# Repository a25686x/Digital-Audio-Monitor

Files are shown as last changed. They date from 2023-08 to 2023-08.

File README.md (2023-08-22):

monitor digital audio from SPDIF/AES3 and SDI video source

  CS8416:  select digital audio signals from AES and SDI with BNC and SFP connectors

  SSM3582A:  audio amplifier

  GS2971:  Digital audio demultiplex

  RS2228XN:  select SDI between SFP and BNC conncetor

  ESP8285:  system control

Using following software:

  Kicad 7.0 
  Fusion 360
  Arduino

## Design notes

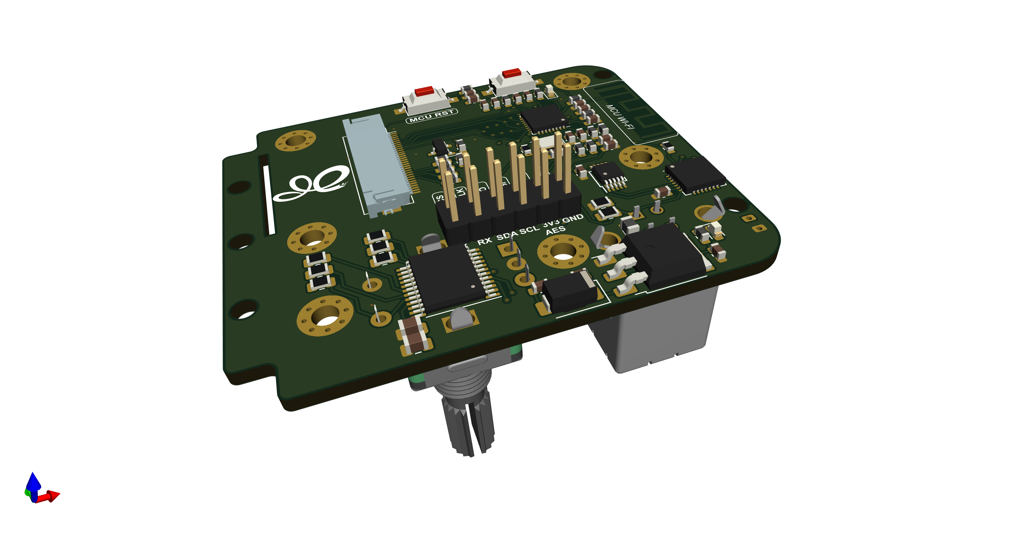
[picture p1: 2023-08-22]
Kicad_Files/MCU/MCU_ROTARY_LCD_CM108AH_20230812EV.png

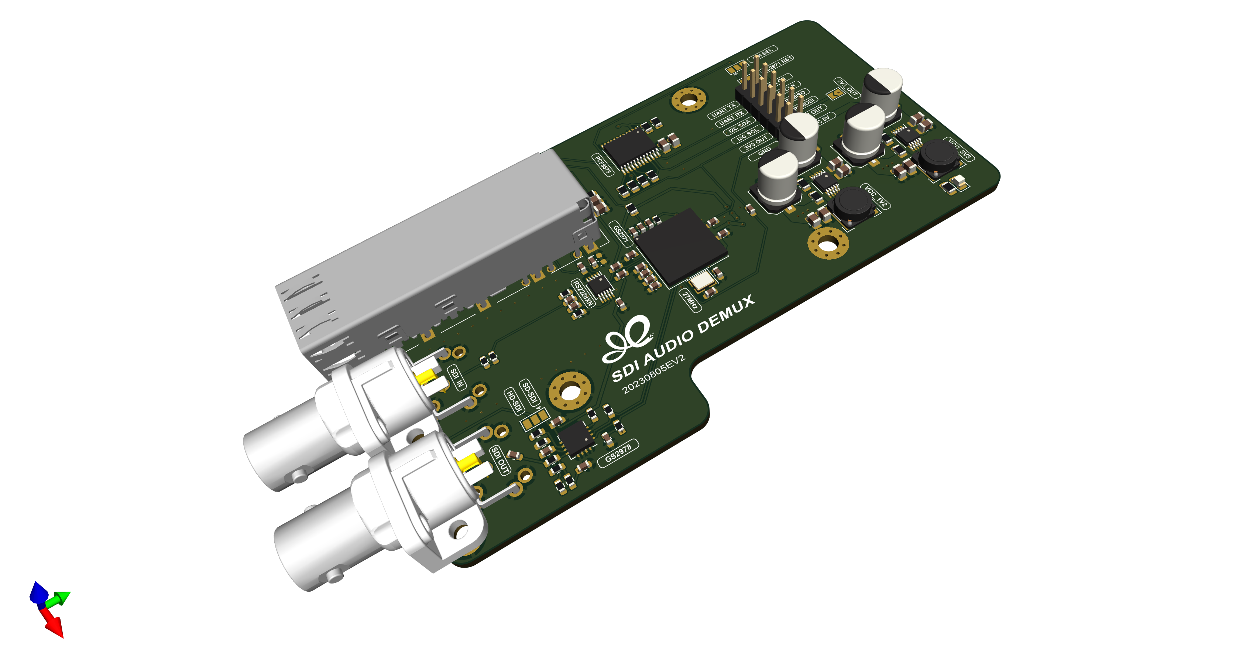
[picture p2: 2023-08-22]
Kicad_Files/SDI_DEMUX_RS2228XN_20230805EV.png

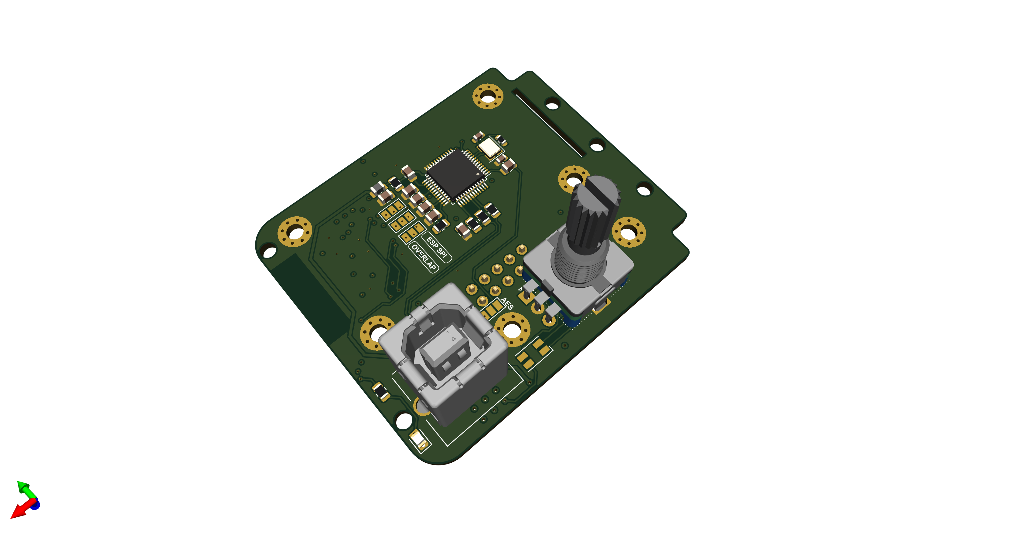
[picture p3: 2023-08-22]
Kicad_Files/MCU/MCU_ROTARY_LCD_CM108AH_20230812EV2.png

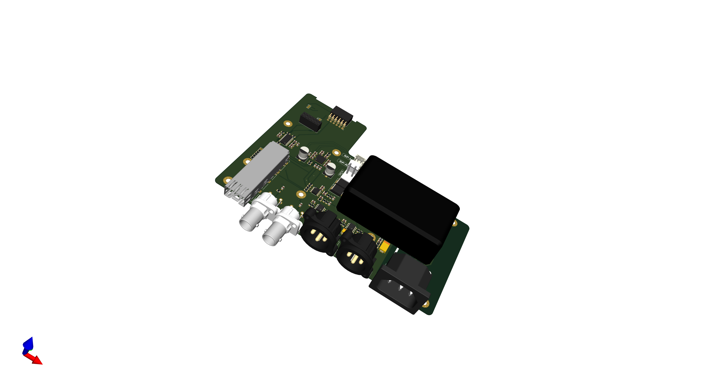
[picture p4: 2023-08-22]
Kicad_Files/MainBoard/AudioMonitor_MB_20230804EV.png

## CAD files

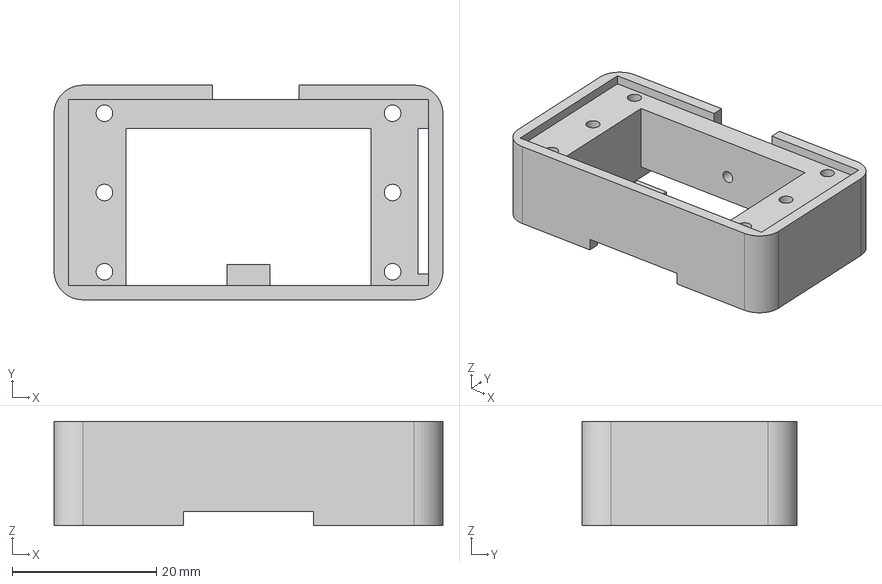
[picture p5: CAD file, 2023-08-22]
3D_STEP_Files/AudioMonitor_LCD_BASE_20230813EV v54.step
54.0 x 29.8 x 14.5 mm

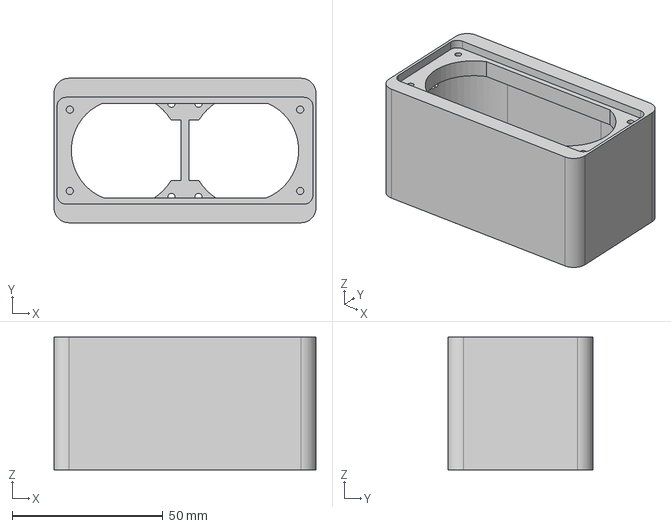
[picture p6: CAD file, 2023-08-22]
3D_STEP_Files/AudioMonitor_BOX_20230811EV v42.step
87.0 x 48.0 x 44.0 mm

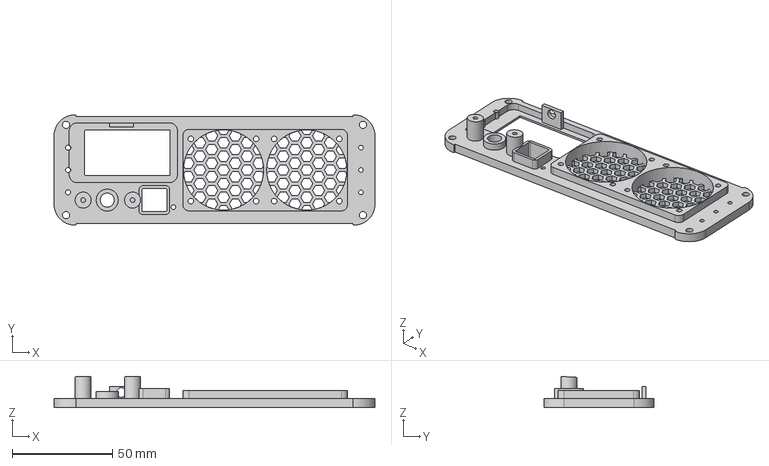
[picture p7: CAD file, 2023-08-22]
3D_STEP_Files/AudioMonitor_Panel_20230814EV_END_+0.5MM.step
160.0 x 55.0 x 15.5 mm

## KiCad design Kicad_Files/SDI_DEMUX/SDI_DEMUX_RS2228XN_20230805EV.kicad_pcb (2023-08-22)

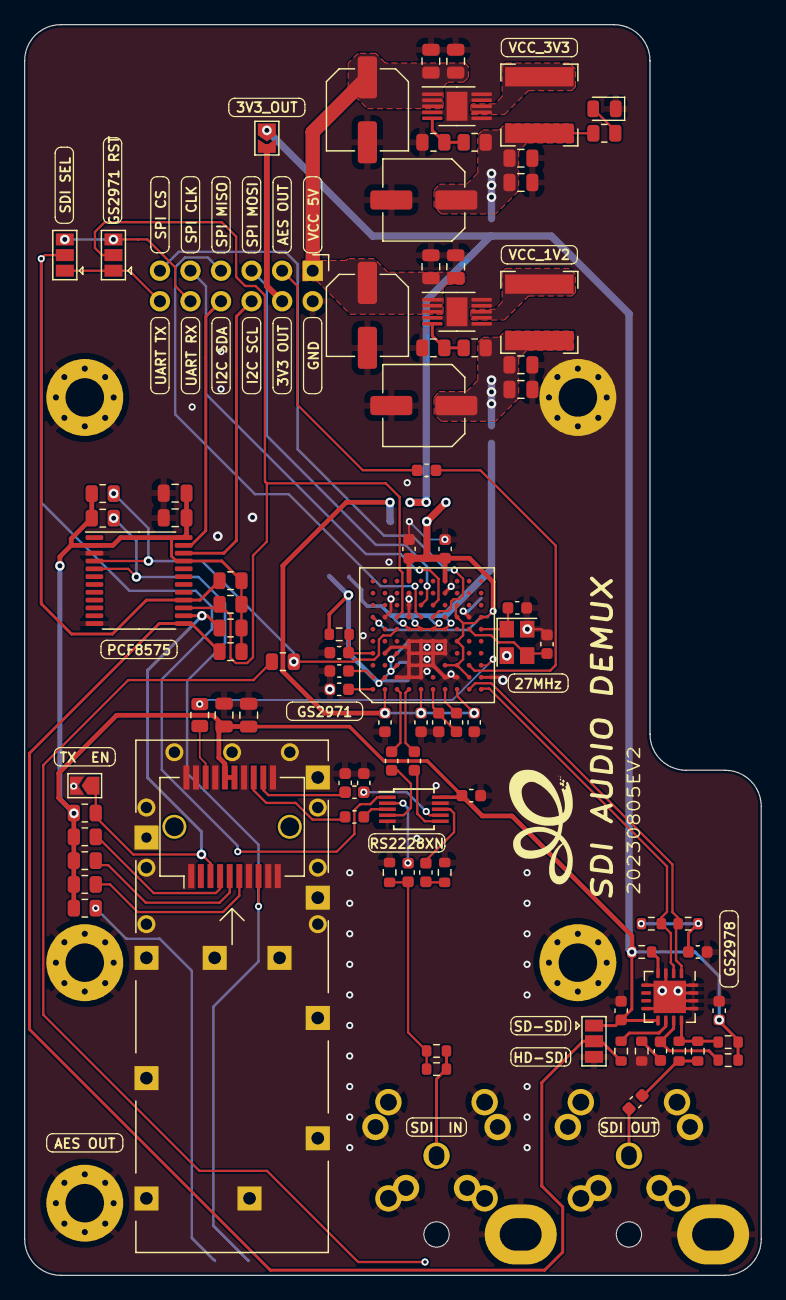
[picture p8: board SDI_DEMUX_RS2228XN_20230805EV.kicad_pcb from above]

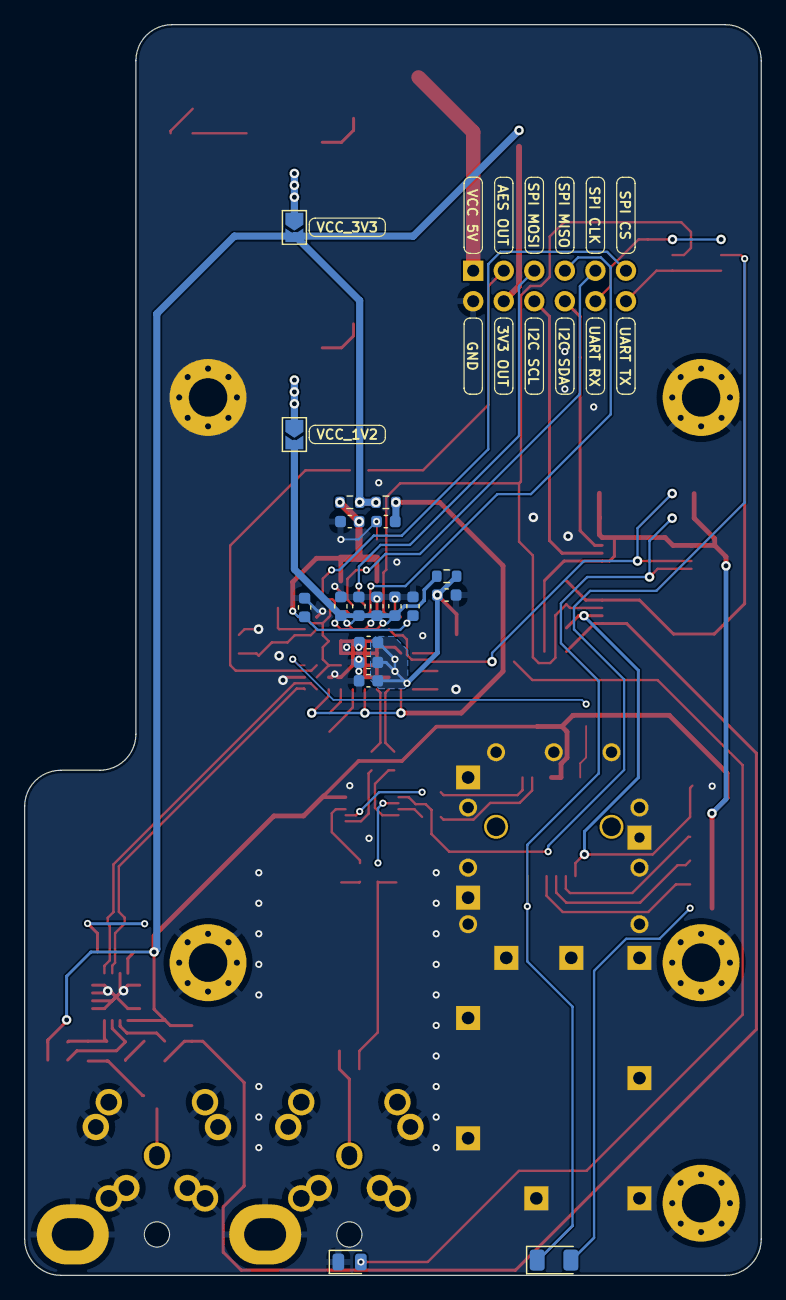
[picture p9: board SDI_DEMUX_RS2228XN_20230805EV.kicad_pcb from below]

Board: 2 copper layers, 61.2 x 104.0 mm, 118 parts (19 on the bottom side), 68 nets.

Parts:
C10, C26, C31, C42, C49, C51: 105; C_0603_1608Metric
C11, C12, C13, C14, C15, C16, C17, C27, C28, C29, C32, C33, C34, C35, C47, C48, C57: 10n; C_0603_1608Metric
C18: 226; C_0603_1608Metric
C41, C100, C101: 474; C_0603_1608Metric
C43, C44: 16p; C_0603_1608Metric
C50, C52: 475; C_0603_1608Metric
C105: 104; C_0603_1608Metric
C2701, C3302: 106; C_0805_2012Metric
C2702, C3102, C3202, C3301: 104; C_0805_2012Metric
C2711, C2712, C2721, C2722, C2723, C2724, C2731: 106; C_0603_1608Metric
C3101, C3106, C3201, C3206: 105; C_0805_2012Metric
C3103, C3104, C3203, C3204: 107; CP_Elec_6.3x7.7_20230725EV
C3105, C3205: 10n; C_0805_2012Metric
D102, D205: LED; LED_0805_2012Metric
D2701: Fiber RX OK(GREEN); LED_1206_3216Metric
J2701: SDI IN; Connector_SFP_and_Cage_UserEco1_20230723EV
J2702: SDI_OUT; BCJ-BPLHKA_TOP_UserEco1_20230722EV
J2705: SDI_IN; BCJ-BPLHKA_TOP_UserEco1_20230722EV
J3001: Conn_02x06_Odd_Even; PinHeader_2x06_P2.54mm_Vertical
JP1, JP3, JP2702: SolderJumper_3_Open; SolderJumper-3_P1.3mm_Open_Pad1.0x1.5mm
JP2, JP3001, JP3101, JP3201: SolderJumper_2_Open; SolderJumper-2_P1.3mm_Open_TrianglePad1.0x1.5mm
L3: 6.2n; R_0603_1608Metric
L4: 5.6n; R_0603_1608Metric
L3101, L3201: L; L_Bourns-SRN6028
MB3, MB4, MB5, MB6, MB7: MB; MountingHole_3.2mm_M3_Pad_Via_Eco1_20230801EV
R2, R10, R11, R50: 0R; R_0603_1608Metric
R3: 0R; R_0805_2012Metric
R7: 105R; R_0603_1608Metric
R40: 750R; R_0603_1608Metric
R41, R42, R43, R44, R45, R47: 75R; R_0603_1608Metric
R46: 37.4R; R_0603_1608Metric
R48, R49: 49.9; R_0603_1608Metric
R100, R205: 4.7k; R_0805_2012Metric
R2701, R2702, R2703, R2704: 4.7K; R_0805_2012Metric
R2705: 1K; R_0805_2012Metric
R3101: 450K; R_0805_2012Metric
R3102, R3201, R3202, R3301, R3302, R3303, R3304, R3311, R3312: 100K; R_0805_2012Metric
U1: GS2971; BGA-100_11.0x11.0mm_Layout10x10_P1.0mm_Ball0.5mm_Pad0.4mm_N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
U7: GS2978; QFN-16-1EP_4x4mm_P0.65mm_EP2.7x2.7mm
U2702: RS2228XN; MSOP-10_3x3mm_P0.5mm
U3101, U3201: AP2420; MSOP-10-1EP_3x3mm_P0.5mm_EP1.73x2.40mm_20230801EV
U3301: PCF8575PW; TSSOP-24_6.1x7.8mm_P0.65mm
Y1: 27M; Crystal_SMD_3225-4Pin_3.2x2.5mm

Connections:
/+1.2V: C14.1, C15.1, C16.1, C17.1, JP3201.2 (B), R10.2, U1.D6 (CORE_VDD), U1.E6 (CORE_VDD), U1.F6 (CORE_VDD), U1.G6 (CORE_VDD)
/+1.2VA: C26.1, C27.1, C28.1, C29.1, R7.2, R10.1, U1.B2 (PLL_VDD), U1.C3 (PLL_VDD), U1.C4 (PLL_VDD)
/+3.3VA: C10.1, C11.1, C12.1, C13.1, R2.1, U1.B1 (A_VDD), U1.E1 (SDI_VDD), U1.H1 (BUF_VDD)
/AES_SFP_TX+: J2701.18 (TD+), R3.1
/AOUT_1/2: C105.2, J3001.4
/AOUT_3/4: R3.2, U1.K3 (AOUT_3/4)
/GS2971_IN+: C2711.2, U1.C1 (SDI+)
/GS2971_IN-: C2712.2, U1.D1 (SDI-)
/GS2971_RST: JP1.2 (C), R3303.1, U1.C7 (RESET-), U3301.15 (P12)
/GS2971_STAT5: R205.2, R3311.2, U1.C6 (STAT5), U3301.4 (P00)
/IO_VDD: C31.1, C32.1, C33.1, C34.1, C35.1, R11.1, U1.A7 (IO_VDD), U1.D10 (IO_VDD), U1.G3 (RC_BYP), U1.G10 (IO_VDD), U1.H3 (AUDIO_EN/DIS), U1.H5 (TIM_861), U1.H7 (20BIT_10BIT), U1.H8 (IOPROC_EN/DIS), U1.J2 (SDO_EN/DIS), U1.K7 (IO_VDD)
/MCU_3V3_OUT: J3001.3, JP3001.2 (B)
/MCU_I2C_SCL: J3001.5, U3301.22 (SCL)
/MCU_I2C_SDA: J3001.7, U3301.23 (SDA)
/MCU_SPI_CLK: J3001.10, U1.F8 (SCLK_TCK)
/MCU_SPI_CS: J3001.12, U1.F7 (CS_TMS)
/MCU_SPI_MISO: J3001.8, U1.E7 (SDOUT_TDO)
/MCU_SPI_MOSI: J3001.6, U1.E8 (SDIN_TDI)
/MCU_UART_RX: J3001.9, JP1.3 (B), JP2702.3 (B)
/MCU_UART_TX: J3001.11, JP1.1 (A), JP2702.1 (A)
/SDI_IN+: C49.2, U2702.2 (HSD0_P)
/SDI_IN-: C51.2, U2702.8 (HSD0_M)
/SDI_INPUT_SELECT: JP2702.2 (C), R3304.1, U2702.1 (SEL), U3301.16 (P13)
/SDO+: R49.1, U1.J1 (SDO+), U7.1 (SDI+)
/SDO-: R48.1, U1.K1 (SDO-), U7.2 (SDI-)
/SD_HD_SLEW: JP3.2 (C), R50.2, R3301.1, U3301.13 (P10)
/SFP_RD+: C2721.1, J2701.13 (RD+)
/SFP_RD-: C2722.1, C2723.2, J2701.12 (RD-)
/SFP_RX_LOSS: D2701.1 (K), J2701.8 (RX_LOS), R3312.2, U3301.5 (P01)
/SFP_TX_DISABLE: J2701.3 (TX_DISABLE), JP2.1 (A), R2704.2, R3302.1, U3301.14 (P11)
/VCC5V_IN: C3101.1, C3102.1, C3103.1, C3201.1, C3202.1, C3203.1, J3001.2, U3101.1 (EN), U3101.2 (VDD), U3101.3 (PVDD), U3201.1 (EN), U3201.2 (VDD), U3201.3 (PVDD)
/VCC_3.3V: C47.1, C48.1, C2701.1, C2702.1, C2731.1, C3301.1, C3302.1, J2701.15 (VccR), J2701.16 (VccT), JP3.1 (A), JP3001.1 (A), JP3101.2 (B), R2.2, R11.2, R40.1, R41.1, R43.1, R2701.1, R2702.1, R2703.1, R2704.1, R2705.2, R3301.2, R3302.2, R3303.2, R3304.2, R3311.1, R3312.1, U7.9 (VCC), U2702.10 (VCC), U3301.2 (A1), U3301.21 (A0), U3301.24 (VCC)
GNDD: C10.2, C11.2, C12.2, C13.2, C14.2, C15.2, C16.2, C17.2, C18.2, C26.2, C27.2, C28.2, C29.2, C31.2, C32.2, C33.2, C34.2, C35.2, C41.1, C42.1, C43.2, C44.1, C47.2, C48.2, C57.2, C101.1, C2701.2, C2702.2, C2723.1, C2724.1, C2731.2, C3101.2, C3102.2, C3103.2, C3104.2, C3105.2, C3106.2, C3201.2, C3202.2, C3203.2, C3204.2, C3205.2, C3206.2, C3301.2, C3302.2, D102.1 (K), D205.1 (K), J2701.1 (VeeT), J2701.7 (RS0), J2701.9 (RS1), J2701.10 (VeeR), J2701.11 (VeeR), J2701.14 (VeeR), J2701.17 (VeeT), J2701.19 (TD-), J2701.20 (VeeT), J2701.CAGE, J2702.2 (Ext), J2705.2 (Ext), J3001.1, JP2.2 (B), JP3.3 (B), MB3.1, MB4.1, MB5.1, MB6.1, MB7.1, R44.1, R45.2, R46.2, R3102.2, R3202.2, U1.B4 (VCO_GND), U1.B7 (IO_GND), U1.C2 (A_GND), U1.D2 (A_GND), U1.D3 (A_GND), U1.D4 (PLL_GND), U1.D5 (CORE_GND), U1.D7 (SW_EN), U1.D8 (JTAG/HOST), U1.D9 (IO_GND), U1.E2 (SDI_GND), U1.E3 (A_GND), U1.E4 (PLL_GND), U1.E5 (CORE_GND), U1.F3 (A_GND), U1.F4 (PLL_GND), U1.F5 (CORE_GND), U1.G2 (A_GND), U1.G4 (CORE_GND), U1.G5 (CORE_GND), U1.G9 (IO_GND), U1.H2 (BUF_GND), U1.J7 (IO_GND), U1.K2 (STANDBY), U7.3 (GND), U7.5 (NC), U7.8 (NC), U7.13 (NC), U7.14 (NC), U7.15 (NC), U7.16 (NC), U7.17 (TAB), U2702.5 (GND), U2702.9 (nOE), U3101.4 (GND), U3101.6 (GND), U3101.9 (PGND), U3101.10 (PGND), U3101.11 (GND), U3201.4 (GND), U3201.6 (GND), U3201.9 (PGND), U3201.10 (PGND), U3201.11 (GND), U3301.3 (A2), U3301.12 (GND), Y1.2, Y1.4
unnamed: C49.1, L3.2, R42.1, R45.1
unnamed: C50.2, R44.2
unnamed: C51.1, R46.1
unnamed: C52.1, L4.2, R47.1
unnamed: C57.1, R48.2, R49.2
unnamed: D102.2 (A), R100.2
unnamed: D205.2 (A), R205.1
unnamed: D2701.2 (A), R2705.1
unnamed: J2701.6 (MOD_ABS), R2703.2
unnamed: J2701.5 (SCL), R2702.2
unnamed: J2701.4 (SDA), R2701.2
unnamed: C52.2, J2702.1 (In)
unnamed: J2705.1 (In), L3.1, R42.2
unnamed: C3104.1, C3105.1, C3106.1, JP3101.1 (A), L3101.2, R100.1, R3101.1
unnamed: C3204.1, C3205.1, C3206.1, JP3201.1 (A), L3201.2, R3201.1
unnamed: L3101.1, U3101.7 (LX), U3101.8 (LX)
unnamed: L3201.1, U3201.7 (LX), U3201.8 (LX)
unnamed: C100.1, C101.2, U1.F1 (AGC+)
unnamed: C100.2, U1.G1 (AGC-)
unnamed: C105.1, U1.J3 (AOUT_1/2)
unnamed: C41.2, U1.A2 (LF)
unnamed: C42.2, U1.A1 (VBG)
unnamed: C18.1, R7.1, U1.A4 (VCO_VDD)
unnamed: C44.2, U1.K6 (XTAL1), Y1.1
unnamed: C43.1, U1.J6 (XTAL2), Y1.3
unnamed: R40.2, U7.4 (RSET)
unnamed: L4.1, R41.2, R47.2, U7.12 (SDO+)
unnamed: C50.1, R43.2, U7.11 (SDO-)
unnamed: R50.1, U7.10 (SD/HD)
unnamed: C2712.1, U2702.6 (D_N)
unnamed: C2711.1, U2702.4 (D_P)
unnamed: C2722.2, C2724.2, U2702.7 (HSD1_M)
unnamed: C2721.2, U2702.3 (HSD1_P)
unnamed: R3101.2, R3102.1, U3101.5 (FB)
unnamed: R3201.2, R3202.1, U3201.5 (FB)

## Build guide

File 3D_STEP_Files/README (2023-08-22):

step files export from Fusion 360 for 3D print

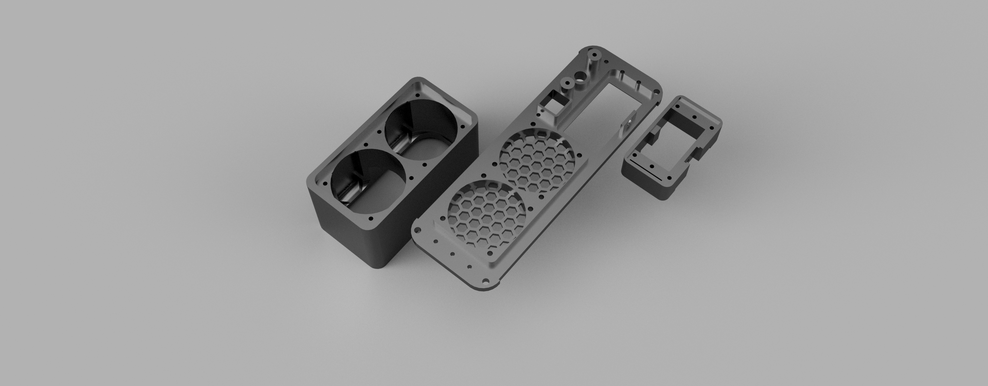
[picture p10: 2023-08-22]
3D_STEP_Files/AudioMonitor_Panel_20230719EV v54.png

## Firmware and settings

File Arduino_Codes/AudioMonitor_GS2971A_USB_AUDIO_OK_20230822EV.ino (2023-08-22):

#include "Arduino.h"
#include "PCF8575.h"
#include <Wire.h>
#include <Adafruit_PWMServoDriver.h>
#include <SPI.h>
#include <EEPROM.h>


#include <TFT_eSPI.h>




//顶部标题信息显示
String str_TopHeader = "AUDIO   GEARBOX   PRO";



//GS2971A SPI数据读取
char SPI_READ_VALUE[48] = {0};


//实例化TFT_eSPI
TFT_eSPI tft  = TFT_eSPI();

//LCD时间显示最大计数复位
#define MAX_TIME_COUNT    86400



//最大音量限制
#define SSM3582A_MAX_OUTPUT_VOLUME   245


//信号数量定义
#define INPUT_SIGNAL_COUNT   5

//信号接口及信号类型定义
String str_AudioSource[INPUT_SIGNAL_COUNT][2] = {
  {"AES", "BNC-1"},
  {"AES", "SFP-1"},
  {"SDI", "BNC-2"},
  {"SDI", "SFP-2"},
  {"USB", "FRONT"}
};








//CS8416复位控制引脚:GPIO3(ESP8285_UART_RX)
//CS8416复位控制引脚:GPIO1(ESP8285_UART_TX)
//CS8416复位控制引脚:GPIO2(ESP8285_SPI_CS)


//*********GS2971与CS8416采用同一复位引脚*********//
#define CS8416_GS2971_RESET_PIN    1










//CS8416锁定状态ESP8285检测GPIO端口(GPIO16)
//设置cs8416寄存器6第4位(UNLOCKM)掩码为1，设置GPIO0输出为RERR，通过CS8416 GPIO0端口输出信号锁定状态
#define CS8416_LOCKED_DETECT_PIN  16
//CS8416上次检测锁定状态
int   last_CS8416_lock_status = 0;
//CS8416锁定状态
int   CS8416_lock_status = 0;


//CS8416 I2C地址
#define  CS8416_I2C_ADDRESS   0x14


//信号输入端口定义
int RX_PORT[INPUT_SIGNAL_COUNT] = {0x00, 0x08, 0x10, 0x10, 0x18};

//信号输出端口定义
int TX_PORT[INPUT_SIGNAL_COUNT] = {0x00, 0x01, 0x02, 0x02, 0x03};


//BNC接口及FC接口AES信号输出源索引
//  0:  BNC接口输入
//  1:  FC光纤输入
//  2:  BNC接口SDI输入音频解嵌输出
//  3:  FC光纤接口SDI输入音频解嵌输出
int   n_AES_TX_Index = 0;

//监听AES信号输入源索引
//  0:  BNC接口输入
//  1:  FC光纤输入
//  2:  BNC接口SDI输入音频解嵌输出
//  3:  FC光纤接口SDI输入音频解嵌输出
int   n_AES_monitor_Index = 2;






#include <PolledTimeout.h>

#define ESP8285_SDA_PIN 4
#define ESP8285_SCL_PIN 5

//ESP8285 I2C地址(可选)
const int16_t ESP8285_I2C_MASTER_ADDRESS = 0x42;





//SSM3582A初始音量设置
int n_SSM3582A_vol = 0x80;

//GS12070 SPI Control SS PIN
int GPIO_SPI_CS = 10;














//LED闪烁间隔
unsigned long LedFlash_Time = {0};
int   LedFlashControl = 0;
int   LedFlashInterval = 500;
int   FlashInterval = 500;










//信息刷新显示间隔
int  infoUpdate_Interval = 1000;
unsigned long infoUpdate_Time = 0;





















//**********串口数据读取**********
char str_ReadCommand[200];
int nIndex = 0;




/*************************************************************/
//TLC5615 SPI控制引脚
const int CS_PIN = 2;   // 片选引脚
const int CLK_PIN = 14;  // 时钟引脚
const int DATA_PIN = 13; // 数据引脚
/*************************************************************/





/*************************************************************/
//旋转编码器变量定义
int encoderPos = 0;
//前一个计数值（-----当计数值未变化时不刷新显示或执行操作-----）
int last_encoderPos = 0;

//编码器状态
int encoderState = 0;
int lastEncoded = 0;

//编码器各引脚状态值
int encoderPinAState;
int encoderPinBState;
int encoderPinSWState;

//编码器SW按钮按下计数
int   n_EC11_Index = 0;



//数值是否改变标志
bool  b_value_changed = false;
/*************************************************************/






/*
  0x18ce  //午夜蓝
  0x22f   //水手蓝
  0x18a   //普鲁士蓝
  0x194
  0x4004    //勃艮第红
  0x5345    //暗橄榄绿
  0x6199    //紫水晶色
  0x49c0    //咖啡色
  0x62ca    //铁灰色
  0x48e0    //椰褐色
  0xcfe0    //亮柠檬色
  0x9806    //紫红
  0xa7f9    //苍色
  0xc618    //银色
  0xf7be    //白烟色
  0xcaa0    //燃橙
  0xff59    //杏仁白
*/

//顶部标题显示背景色
int top_BG = 0x9806; //紫红
//int top_BG = 0xcfe0; //亮柠檬色
int top_FG = TFT_WHITE;
//int top_FG = 0xa7f9; //苍色
//int top_FG = 0xcfe0; //亮柠檬色
uint8_t top_Font = 4;
int top_MC_OFFSET = 3; //文字显示垂直偏移





//频率显示背景色
int freq_BG = 0x48e0; //椰褐色
int freq_FG = 0xc618;  //银色
uint8_t freq_Font = 4;
int freq_MC_OFFSET = 5; //文字显示垂直偏移

//电压显示背景色
int voltage_BG = 0x18a; //普鲁士蓝
//int voltage_FG = TFT_WHITE;
int voltage_FG = 0xc618;  //银色
uint8_t voltage_Font = 4;
int voltage_MC_OFFSET = 3; //文字显示垂直偏移




//信号源选择显示背景色
int audio_BG = 0x18a; //普鲁士蓝
int audio_FG = 0xc618;  //银色
uint8_t audio_Font = 4;
int audio_MC_OFFSET = 3; //文字显示垂直偏移




//电流显示背景色
int amps_BG = 0x4004; //勃艮第红
//int amps_FG = TFT_WHITE;
int amps_FG = 0xc618;  //银色
uint8_t amps_Font = 4;
int amps_MC_OFFSET = 3; //文字显示垂直偏移




//输出功率显示背景色
int fwd_BG = 0x5345;  //暗橄榄绿
//int fwd_FG = 0xcaa0;  //燃橙
int fwd_FG = 0xff59;  //杏仁白
//int fwd_FG = 0xc618;  //银色
//int fwd_FG = 0xf7be;  //白烟色
uint8_t fwd_Font = 4;
int fwd_MC_OFFSET = 8; //文字显示垂直偏移



//运行时间显示背景色
int time_BG = 0x2a69; //暗岩灰
int time_BG2 = 0x11;  //暗蓝
int time_FG = 0xcfe0; //亮柠檬色
uint8_t time_Font = 7;

//时钟刷新定时间隔
unsigned long clock_Time = 0;
int   ClockInterval = 1000;


//系统启动计时
unsigned long n_StartUpTime = 0;



//LCD屏背光设置
int LCD_BLK_VALUE = 140;

//LCD屏幕保护等待时间
unsigned long ScreenSave_Time = 0;
int   ScreenSave_Interval = 30000;



//面板键盘按钮数量定义
#define   KEY_COUNT   6


//按钮消除抖动时间设置
const int DEBOUNCE_DELAY = 50;

//按钮长按时间定义
const int LONG_PRESS_TIME = 2000;




//按钮上一次处于稳定状态时引脚电平
int lastSteadyState[KEY_COUNT + 1] = {HIGH};
//按钮上一次抖动状态时引脚电平
int lastFlickerableState[KEY_COUNT + 1] = {HIGH};
//按钮当前状态引脚电平
int currentState[KEY_COUNT + 1];

//按钮上一次处于抖动状态时间
unsigned long lastDebounceTime[KEY_COUNT + 1] = {0};
//按钮上一次按下时间
unsigned long prevPressTime[KEY_COUNT + 1] = {0};
//当前时间
unsigned long curTime[KEY_COUNT + 1] = {0};









/**********GS2971音频解嵌SPI控制参数**********/
//HD MODE AES OUT CONFIG
//char HD_AES_OUT_CONFIG[4] = {0x02, 0x00, 0x0f, 0x04};
char HD_AES_OUT_CONFIG[4] = {0x02, 0x00, 0x00, 0x00};
//SD MODE AES OUT CONFIG
//char SD_AES_OUT_CONFIG[4] = {0x04, 0x08, 0x00, 0x00};
char SD_AES_OUT_CONFIG[4] = {0x04, 0x08, 0xff, 0x00};

//SATA0-SATA2 PORT MODE SET
//0_XXXXX_XXXXX_XXXXX
//4-0   SATA0_CONFIG
//9-5   SATA1_CONFIG
//14-10 SATA2_CONFIG

//00011:  LOCKED
char SATA_0_1_2_CONFIG[4] = {0x00, 0x08, 0x0c, 0x63};

//SATA3-SATA5 PORT MODE SET
//0_XXXXX_XXXXX_XXXXX
//4-0   SATA3_CONFIG
//9-5   SATA4_CONFIG
//14-10 SATA5_CONFIG

//00011:  LOCKED
char SATA_3_4_5_CONFIG[4] = {0x00, 0x09, 0x0c, 0x63};



//AES OUTPUT CHANNEL CONFIG
//CH1+CH2:  0x208
//CH3+CH4:  0x692
//CH5+CH6:  0xB2C
//CH7+CH8:  0xFBE
//CH1+CH1:  0x000
//CH2+CH2:  0x249
//CH3+CH3:  0x492
//CH4+CH4:  0x6DB
//CH5+CH5:  0x924
//CH6+CH6:  0xB6D
//CH7+CH7:  0xDB6
//CH8+CH8:  0xFFF
char SD_AES_OUT_SELECT_CH1234[4] = {0x04, 0x09, 0x02, 0x08};
char SD_AES_OUT_SELECT_CH5678[4] = {0x04, 0x0A, 0x02, 0x08};

char HD_AES_OUT_SELECT_CH1234[4] = {0x02, 0x0A, 0x02, 0x08};
char HD_AES_OUT_SELECT_CH5678[4] = {0x02, 0x0B, 0x02, 0x08};



char  SPI_CMD[48] = {
  0x80, 0x1F, 0xff, 0xff,
  0x80, 0x20, 0x00, 0x00,
  0x80, 0x21, 0xff, 0xff,
  0x80, 0x22, 0x00, 0x00,
  //0x02, 0x00, 0x0f, 0x04,   //HD AES OUT
  0x02, 0x00, 0x00, 0x00,   //HD AES OUT
  //0x04, 0x08, 0x00, 0x00,   //SD AES OUT
  0x04, 0x08, 0xff, 0x00,   //SD AES OUT(auto 20bit or 24bit)
  0x00, 0x08, 0x0c, 0x63,   //SATA_0_1_2 CONFIG
  0x00, 0x09, 0x0c, 0x63,   //SATA_3_4_5 CONFIG
  0x04, 0x09, 0x02, 0x08,   //SD_AES_OUT_SELECT_CH1234
  0x04, 0x0A, 0x02, 0x08,   //SD_AES_OUT_SELECT_CH5678
  0x02, 0x0A, 0x02, 0x08,   //HD_AES_OUT_SELECT_CH1234
  0x02, 0x0B, 0x02, 0x08,   //HD_AES_OUT_SELECT_CH5678
};



int i_CH = 0;
char CH[12] = {
  0x0000, 0x0249, 0x0492, 0x06db,
  0x0924, 0x0b6d, 0x0db6, 0x0fff,
  0x0208, 0x0692, 0x0b2c, 0x0fbe
};













/***************************2023-08-04******************************/

//SDI子卡GPIO输入输出控制PCF8575 I2C地址
int SDI_CONTROL_PCF8575_I2C_ADDRESS = 0x23;

//SDI子卡GPIO输入输出控制PCF8575实例化
PCF8575 SDI_control_pcf8575(SDI_CONTROL_PCF8575_I2C_ADDRESS);

//GS2971_STAT5状态监测GPIO端口编号
int GS2971_STAT5_STATUS_PORT = 0;
//STAT5端口状态
int GS2971_STAT5_STATUS = 0;

//SFP接收信号中断状态监测GPIO端口编号
int SFP_RX_LOSS_STATUS_PORT = 1;
//RX Loss端口状态
int SFP_RX_LOSS_STATUS = 0;

//LMH0302 SD/HD SLEW控制GPIO端口编号
int LMH0302_SLEW_CONTROL_PORT = 8;

//SFP发送信号允许控制GPIO端口编号
int SFP_TX_ENABLE_PORT = 9;

//GS2971芯片复位控制GPIO端口编号
int GS2971_RESET_CONTROL_PORT = 10;

//RS22228XN SDI输入选择控制GPIO端口编号
int RS2228XN_INPUT_SELECT_PORT = 11;

//GS2971A SPI 控制片选引脚ESP8285 GPIO端口编号
int ESP8285_GS2971_GPIO_SPI_CS = 2;


//SDI子卡PCF8575状态一次性读取
PCF8575::DigitalInput SDI_pcf8575_di;






//AudioMonitor音频功放键盘检测PCF8575 I2C地址
int PCF8575_I2C_ADDRESS = 0x21;

//面板旋转编码器状态监测PCF8575实例化
PCF8575 pcf8575(PCF8575_I2C_ADDRESS);


//按钮数组定义，其中第0位代表旋转编码器按钮，其余6位代表6个键盘按钮
int PCF8575_GPIO_CH[KEY_COUNT + 1] = {P15, P0, P1, P2, P3, P4, P5};

//PCF8575一次性读取
PCF8575::DigitalInput pcf8575_di;







//旋转编码器与PCF8575引脚定义
#define   ENCODER_ROT_A   P13
#define   ENCODER_ROT_B   P14
//#define   ENCODER_SW    P15

//选择编码器状态读取
int ROT_A_State;
int ROT_A_LastState;
int ROT_B_State;
int ROT_SW_State;





//提示信息显示
String  strInfo = "";

//文本内容屏幕显示宽度
int string_W;
//文本内容屏幕显示高度
int string_H;




//LCD屏幕长宽参数
int   LCD_W = 320;
int   LCD_H = 170;

//屏幕显示区域水平间隔
int   H_SPACE = 8;

//屏幕显示区域垂直间隔
int   V_SPACE = 7;


//顶部标题栏高度
int   H_Top = 36;
//顶部标题栏宽度
int   W_Top = LCD_W;

//左侧三列显示高度
int   H_Left = (LCD_H - H_Top - V_SPACE * 3) / 3;

//左侧三列显示宽度
int   W_Left = (LCD_W - H_SPACE) * 38 / 100;

//右侧三列显示高度
int   H_Right = (LCD_H - H_Top - V_SPACE * 2) / 2;

//右侧三列显示宽度
int   W_Right = LCD_W - H_SPACE - W_Left;

















//*********************SPI控制命令发送*********************
void SPI_SEND_CMD(char CMD[], int SPI_delay = 5)
{
  SPI.begin();

  digitalWrite(GPIO_SPI_CS, LOW);
  //delay(5);
  for (int i = 0; i < 6; i++)
  {
    SPI.transfer(CMD[i]);
  }
  digitalWrite(GPIO_SPI_CS, HIGH);
  //delay(SPI_delay);
  delayMicroseconds(500);

  SPI.end();
}



//*********************I2C写数据操作*********************
void I2C_EXECUTE_WRITE_CMD(int i2c_addr, char reg_addr, char command)
{
  Wire.beginTransmission(i2c_addr);
  Wire.write(reg_addr);
  Wire.write(command);
  Wire.endTransmission();
  delayMicroseconds(500);
}



//*********************I2C写数据操作*********************
void I2C_EXECUTE_WRITE_CMD(int i2c_addr, char reg_addr)
{
  Wire.beginTransmission(i2c_addr);
  Wire.write(reg_addr);
  //Wire.read();
  Wire.endTransmission();
  delayMicroseconds(500);
}



//*********************I2C读数据操作*********************
void I2C_EXECUTE_READ_CMD(int i2c_addr)
{
  //Wire.beginTransmission(i2c_addr + 1);
  //Wire.requestFrom(i2c_addr + 1, 1);
  Wire.beginTransmission(i2c_addr);
  Wire.requestFrom(i2c_addr, 1);

  ///2023-02-08 ADD
  Wire.read();
  ///

  Wire.endTransmission();
  delayMicroseconds(500);
}




//*********************向指定地址的I2C器件指定寄存器写入数据*********************
void I2C_SEND_COMMAND(int i2c_addr, char reg_addr, char command)
{
  //STEP:1
  Wire.beginTransmission(i2c_addr);
  Wire.write(reg_addr);
  //Wire.read();
  Wire.endTransmission();
  delayMicroseconds(500);

  //STEP:2
  //Wire.beginTransmission(i2c_addr + 1);
  //Wire.requestFrom(i2c_addr + 1, 1);

  Wire.beginTransmission(i2c_addr);
  Wire.requestFrom(i2c_addr, 1);

  /////////////
  Wire.read();


  Wire.endTransmission();
  delayMicroseconds(500);

  //STEP:3
  Wire.beginTransmission(i2c_addr);
  Wire.write(reg_addr);
  Wire.write(command);
  Wire.endTransmission();
  delayMicroseconds(500);
}





//*********************向指定地址的I2C器件指定寄存器写入数据(数据含掩码)*********************
void I2C_SEND_COMMAND_V2(int i2c_addr, char reg_addr, char command, char mask)
{
  //STEP:1
  Wire.beginTransmission(i2c_addr);
  Wire.write(reg_addr);
  //Wire.read();
  Wire.endTransmission();
  delayMicroseconds(500);

  //STEP:2
  //Wire.beginTransmission(i2c_addr + 1);
  //Wire.requestFrom(i2c_addr + 1, 1);

  Wire.beginTransmission(i2c_addr);
  Wire.requestFrom(i2c_addr, 1);
  Wire.read();

  Wire.endTransmission();
  delayMicroseconds(500);

  //STEP:3
  Wire.beginTransmission(i2c_addr);
  Wire.write(reg_addr);
  Wire.write(command);
  Wire.write(mask);
  Wire.endTransmission();
  delayMicroseconds(500);
}



































/*************************************************************/
//获取系统启动时间并转换为时码格式显示
String GET_RUNING_TIME()
{
  String ss;
  int nSec = ((millis() - n_StartUpTime) / 1000) % MAX_TIME_COUNT;
  int t_s = nSec % 60;

  if (t_s < 10)
  {
    ss = "0" + String(t_s);
  }
  else
  {
    ss = String(t_s);
  }

  return String(nSec / 60) + ":" + ss;
}




/*************************************************************/
void I2C_SCAN()
{
  //I2C DEVICE SCAN
  int nDevices = 0;

  Serial.println("Scanning...");

  for (byte address = 1; address < 127; ++address)
  {
    // The i2c_scanner uses the return value of
    // the Write.endTransmisstion to see if
    // a device did acknowledge to the address.
    Wire.beginTransmission(address);
    byte error = Wire.endTransmission();

    if (error == 0)
    {
      Serial.print("I2C device found at address 0x");
      if (address < 16)
      {
        Serial.print("0");
      }

      Serial.print(address, HEX);
      Serial.println("  !");

      ++nDevices;
    }
    else if (error == 4)
    {
      Serial.print("Unknown error at address 0x");
      if (address < 16) {
        Serial.print("0");
      }
      Serial.println(address, HEX);
    }
  }

  if (nDevices == 0)
  {
    Serial.println("No I2C devices found\n");
  }
  else
  {
    Serial.println("done\n");
  }
}















/*更新音量输出设置*/
void update_volume(int nVol)
{
  //背景色
  //tft.fillRect(W_Left + V_SPACE, H_Top + V_SPACE, W_Right, H_Right, fwd_BG);
  //tft.fillRect(W_Left + V_SPACE, H_Top + V_SPACE, W_Right, H_Right, fwd_BG);
  //tft.fillRect(W_Left + V_SPACE, H_Top + V_SPACE, W_Right, H_Right, fwd_BG);

  //音量柱前景色
  tft.fillRect(W_Left + V_SPACE, H_Top + V_SPACE, W_Right * nVol / 100, H_Right, TFT_GREEN);

  //背景色
  tft.fillRect(W_Left + V_SPACE + W_Right * nVol / 100, H_Top + V_SPACE, W_Right - W_Right * nVol / 100, H_Right, fwd_BG);

  /*
    tft.setFreeFont(&FreeSansBold18pt7b);
    tft.setTextColor(fwd_FG);
    strInfo = String(nVol) ;
    string_W = tft.textWidth(strInfo);
    string_H = tft.fontHeight();
    tft.drawString(strInfo, LCD_W - string_W - (W_Right - string_W) / 2, H_Top + V_SPACE * 1 + H_Right * 0 + (H_Right - string_H) / 2 + fwd_MC_OFFSET);
  */
}








//左第二行
/*更新选择信号类型显示*/
void update_AudioInput_type(int n_AudioSource_Index)
{
  tft.fillRect(0, H_Top + V_SPACE, W_Left, H_Left, freq_BG);
  tft.fillRect(0, H_Top + V_SPACE, W_Left, H_Left, freq_BG);
  tft.fillRect(0, H_Top + V_SPACE, W_Left, H_Left, freq_BG);

  tft.setTextFont(4);

  strInfo = str_AudioSource[n_AudioSource_Index][0];

  tft.setTextColor(freq_FG);
  string_W = tft.textWidth(strInfo);
  string_H = tft.fontHeight();
  tft.drawString(strInfo, (W_Left - string_W) / 2, H_Top + V_SPACE + (H_Left - string_H) / 2 + freq_MC_OFFSET, 4);
}



//左第三行
/*更新信号输入接口显示*/
void update_AudioInput_connector(int n_AudioSource_Index)
{
  tft.fillRect(0, H_Top + V_SPACE * 2 + H_Left * 1, W_Left, H_Left, audio_BG);
  tft.fillRect(0, H_Top + V_SPACE * 2 + H_Left * 1, W_Left, H_Left, audio_BG);
  tft.fillRect(0, H_Top + V_SPACE * 2 + H_Left * 1, W_Left, H_Left, audio_BG);
  tft.setTextFont(4);
  //tft.setTextColor(audio_FG);
  tft.setTextColor(TFT_GOLD);

  strInfo = str_AudioSource[n_AudioSource_Index][1];

  string_W = tft.textWidth(strInfo);
  string_H = tft.fontHeight();
  tft.drawString(strInfo, (W_Left - string_W) / 2, H_Top + V_SPACE * 2 + H_Left * 1 + (H_Left - string_H) / 2 + audio_MC_OFFSET, 4);
}




//左第四行
/*更新信号锁定状态显示*/
void update_AES_locked_status(int locked)
{
  tft.fillRect(0, H_Top + V_SPACE * 3 + H_Left * 2, W_Left, H_Left, amps_BG);
  tft.setTextFont(4);

  if (locked == 0)
  {
    //信号锁定
    strInfo = "LOCKED";
    tft.setTextColor(TFT_ORANGE);
    //tft.setTextColor(TFT_GREENYELLOW);
  }
  else
  {
    //信号未锁定
    strInfo = "UNLOCK";
    tft.setTextColor(TFT_RED);
  }
  string_W = tft.textWidth(strInfo);
  string_H = tft.fontHeight();
  tft.drawString(strInfo, (W_Left - string_W) / 2, H_Top + V_SPACE * 3 + H_Left * 2 + (H_Left - string_H) / 2 + amps_MC_OFFSET, 4);
}




/*更新顶部标题栏显示*/
void update_TopHeader()
{
  //设置字体
  tft.setTextFont(4);
  //tft.setFreeFont(&FreeSansBold12pt7b);
  //tft.setFreeFont(&FreeMonoBold12pt7b);
  //tft.setFreeFont(&FreeSerifBold12pt7b);

  //顶部局部填充（标题信息显示）
  tft.fillRect(0, 0, W_Top, H_Top, top_BG);

  //顶部标题信息阴影显示
  tft.setTextColor(TFT_BLACK);
  tft.drawString(str_TopHeader, (LCD_W - tft.textWidth(str_TopHeader)) / 2 + 2, (H_Top - tft.fontHeight()) + 2 - top_MC_OFFSET, 4);
  //tft.drawString(str_TopHeader, (LCD_W - tft.textWidth(str_TopHeader)) / 2 + 2, (H_Top - tft.fontHeight()) + 2+top_MC_OFFSET);

  //顶部标题信息显示
  tft.setTextColor(top_FG);
  tft.drawString(str_TopHeader, (LCD_W - tft.textWidth(str_TopHeader)) / 2, (H_Top - tft.fontHeight()) - top_MC_OFFSET, 4);
  //tft.drawString(str_TopHeader, (LCD_W - tft.textWidth(str_TopHeader)) / 2, (H_Top - tft.fontHeight())+top_MC_OFFSET);
}







bool b_chg = true;

/*更新运行时间显示*/
void update_TimeDisplay()
{
  //右第三行局部清屏（运行时间显示）
  //if (b_chg)
  //  {
  tft.fillRect(W_Left + V_SPACE, H_Top + V_SPACE * 2 + H_Right * 1, W_Right, H_Right, time_BG);
  //tft.fillRect(W_Left + V_SPACE, H_Top + V_SPACE * 2 + H_Right * 1, W_Right, H_Right, time_BG);
  //tft.fillRect(W_Left + V_SPACE, H_Top + V_SPACE * 2 + H_Right * 1, W_Right, H_Right, time_BG);
  //  }
  //  else
  //  {
  //    tft.fillRect(W_Left + V_SPACE, H_Top + V_SPACE * 2 + H_Right * 1, W_Right, H_Right, TFT_DARKGREEN);
  //    tft.fillRect(W_Left + V_SPACE, H_Top + V_SPACE * 2 + H_Right * 1, W_Right, H_Right, TFT_DARKGREEN);
  //    tft.fillRect(W_Left + V_SPACE, H_Top + V_SPACE * 2 + H_Right * 1, W_Right, H_Right, TFT_DARKGREEN);
  //  }
  //  b_chg = !b_chg;

  //printf("W_Right=%d   H_Right=%d\r\n", W_Right, H_Right);

  //刷新时间显示
  //时间显示
  tft.setTextFont(7);
  tft.setTextColor(time_FG);

  strInfo = GET_RUNING_TIME();

  //系统启动计时
  string_W = tft.textWidth(strInfo);
  string_H = tft.fontHeight();
  //文字居中显示
  tft.drawString(strInfo, LCD_W - string_W - (W_Right - string_W) / 2, H_Top + V_SPACE * 2 + H_Right * 1 + (H_Right - string_H) / 2, 7);
}
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
void loop()
{
  //背光变暗等待时间
  if ((millis() - ScreenSave_Time) > ScreenSave_Interval)
  {
    //屏幕保护时间达到
    //进入屏幕保护模式
    LCD_ScreenSave(true);
  }




  //时钟刷新定时间隔
  if ((millis() - clock_Time) > ClockInterval)
  {
    clock_Time = millis();

    /*更新运行时间显示*/
    update_TimeDisplay();


    //GS2971A芯片SDI音频解嵌设置
    GS2971A_INIT();
  }






  //CS8416锁定状态ESP8285检测GPIO端口(GPIO16)
  //设置cs8416寄存器6第4位(UNLOCKM)掩码为1，设置GPIO0输出为RERR，通过CS8416 GPIO0端口输出信号锁定状态

  //CS8416锁定状态
  CS8416_lock_status = digitalRead(CS8416_LOCKED_DETECT_PIN);
  if (CS8416_lock_status != last_CS8416_lock_status)
  {
    last_CS8416_lock_status = CS8416_lock_status;

    /*更新信号锁定状态显示*/
    update_AES_locked_status(CS8416_lock_status);
  }

 







  pcf8575_di = pcf8575.digitalReadAll();
  encoderPinAState = pcf8575_di.p13;
  encoderPinBState = pcf8575_di.p14;

  //更新状态机
  if (encoderPinAState != lastEncoded)
  {
    //旋转编码器启动
    //取消屏幕保护
    LCD_ScreenSave(false);


    if (encoderPinBState != encoderPinAState)
    {
      encoderState++;
    }
    else
    {
      encoderState--;
    }

    lastEncoded = encoderPinAState;

    //根据状态机的状态变化更新旋转编码器位置
    if (encoderState == 2 || encoderState == -2)
    {
      if (encoderPinBState == HIGH)
      {
        encoderPos -= 1;
        if (encoderPos <= 0)
        {
          encoderPos = 0;
        }
      }
      else
      {
        encoderPos += 1;
        if (encoderPos >= 100)
        {
          encoderPos = 100;
        }
      }

      encoderState = 0;


      //输出当前位置值
      Serial.println(encoderPos);

      if (encoderPos != last_encoderPos)
      {
        //------值未更改的情况下不刷新显示，以减少画面刷新抖动-------
        update_volume(encoderPos);
      }







      //更改SSM3582A音量设置
      //最大音量限制
      n_SSM3582A_vol = 255 - encoderPos * SSM3582A_MAX_OUTPUT_VOLUME / 100;
      I2C_SEND_COMMAND(0x10, 0x07, n_SSM3582A_vol);
      I2C_SEND_COMMAND(0x10, 0x08, n_SSM3582A_vol);


      //保存当前计数值
      last_encoderPos = encoderPos;
    }
  }




  currentState[0] = pcf8575_di.p15;
  currentState[1] = pcf8575_di.p0;
  currentState[2] = pcf8575_di.p1;
  currentState[3] = pcf8575_di.p2;
  currentState[4] = pcf8575_di.p3;
  currentState[5] = pcf8575_di.p4;
  currentState[6] = pcf8575_di.p5;

  for (int p = 0; p <= KEY_COUNT; p++)
  {
    curTime[p] = millis();
    //currentState[p] = pcf8575.digitalRead(PCF8575_GPIO_CH[p]);
    if (currentState[p] != lastFlickerableState[p])
    {
      //printf("CH[%d]  state changed!  CURRENT=%d\r\n", p, currentState[p]);
      lastDebounceTime[p] = curTime[p];
      lastFlickerableState[p] = currentState[p];
    }

    //去抖动判断
    if ((curTime[p] - lastDebounceTime[p]) > DEBOUNCE_DELAY)
    {
      //超过去抖动时间设定
      if (lastSteadyState[p] == LOW && currentState[p] == HIGH)
      {
        //按钮释放

        if ((curTime[p] - prevPressTime[p]) >= LONG_PRESS_TIME)
        {
          //按钮长按时间超过5秒，保存配置
          EEPROM.begin(10);

          //保存当前选择通道信息到EEPROM
          EEPROM.write(0, byte(n_AES_monitor_Index));
          EEPROM.commit();

          //重新启动
          ESP.restart();
        }


        //检测到按钮按下
        //取消屏幕保护
        LCD_ScreenSave(false);

        //current short press released:
        //execute key click command
        //printf("KEY=%02d\r\n", p);
        switch (p)
        {
          case 0:
            {
              //旋转编码器按钮按下
              //编码器SW按钮按下计数

              //  n_AES_monitor_Index:  监听AES信号输入源索引
              //  0:  BNC接口输入
              //  1:  FC光纤输入
              //  2:  BNC接口SDI输入音频解嵌输出
              //  3:  FC光纤接口SDI输入音频解嵌输出
              n_AES_monitor_Index = (n_AES_monitor_Index + 1) % INPUT_SIGNAL_COUNT;

              //  n_AES_TX_Index:  环串输出信号源索引
              //  0:  BNC接口输入
              //  1:  FC光纤输入
              //  2:  BNC接口SDI输入音频解嵌输出
              //  3:  FC光纤接口SDI输入音频解嵌输出

              //监听联动输出
              n_AES_TX_Index = n_AES_monitor_Index;

              //执行CS8416输入输出信号源选择设置更新
              CS8416_TX_RX_UPDATE();

            }
            break;


          default:
            break;
        }
      }
      else
      {
        if (lastSteadyState[p] == HIGH && currentState[p] == LOW)
        {
          //按钮按下
          //保存按下时间
          prevPressTime[p] = curTime[p];
        }
      }
      lastSteadyState[p] = currentState[p];
    }
  }




  //delay for i2c operation
  delayMicroseconds(500);
}
